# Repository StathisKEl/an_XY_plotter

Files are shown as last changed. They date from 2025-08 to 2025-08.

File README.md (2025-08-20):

An XY plotter that places an array of a Hall sensor and a strong magnet connected to two pieces of soft iron over specific points on a metal sheet and measures the changes in magnetic induction as the above array is moved from one point to another. From the measurements stored on an SD card, as well as the points of interest stored on the same SD card, useful conclusions can be drawn about the condition of the metal sheet.

The code inside the code_XY_plotter.ino file is under the GNU General Public v3.0 license and the hardware of the XY plotter such as the eagle pcb files and the eagle library files is under the CERN Open Hardware Version 2 - Strongly Reciprocal license. Also all the files of the 3D parts are under the Creative Commons Attribution Share Alike 4.0 International license. All the informations about the GNU General Public v3.0 license can be found in the GNU GPLv3 license.txt file, all the informations about the CERN Open Hardware Version 2 - Strongly Reciprocal license can be found in the CERN OHL S 2.0 license.txt file and all the informations about the Creative Commons Attribution Share Alike 4.0 International license can be found in the CC-BY-SA-4.0 license.txt file.

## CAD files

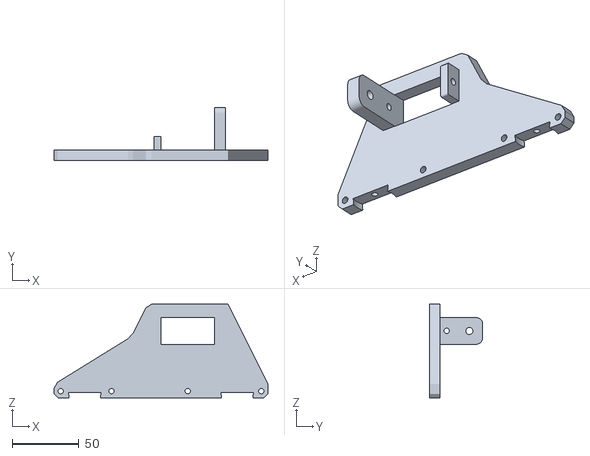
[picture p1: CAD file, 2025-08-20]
3D_printing_files/Base Plate Bottom.stl
160.0 x 40.0 x 70.0

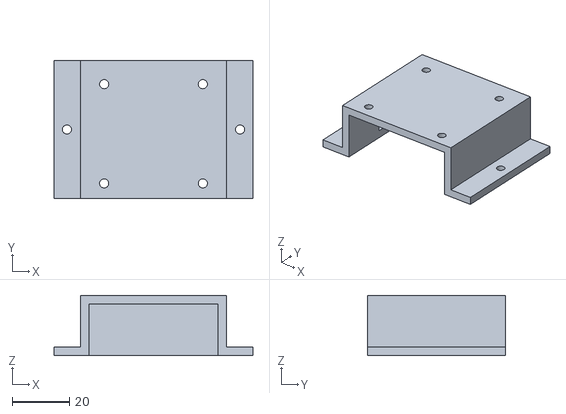
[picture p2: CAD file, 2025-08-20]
3D_printing_files/Sensor Holder Second Part v5.stl
69.4 x 48.0 x 21.0

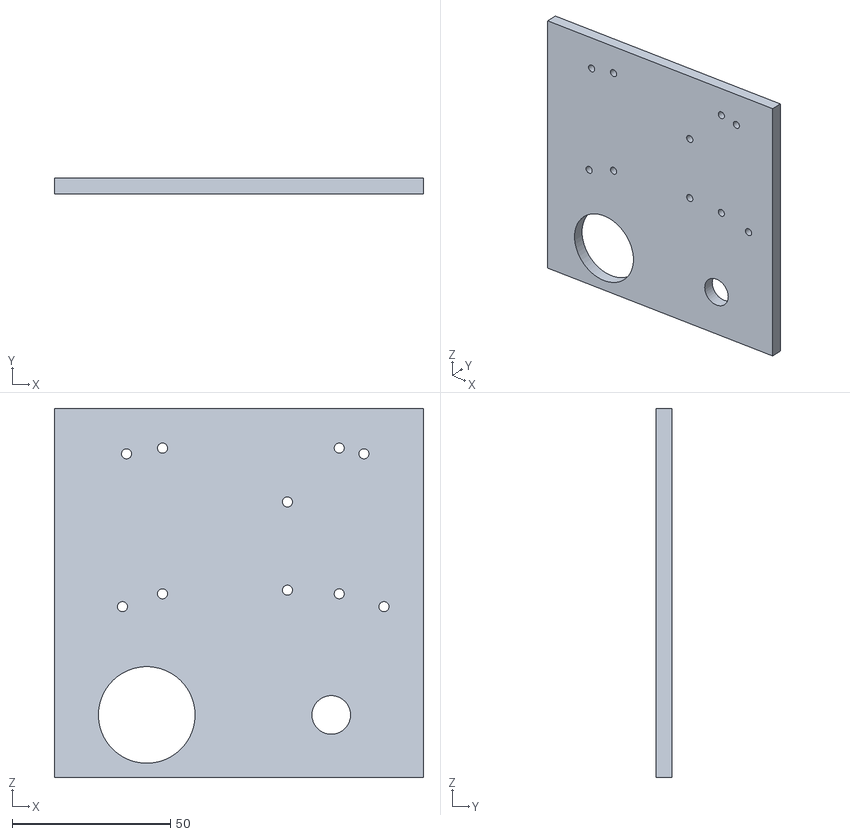
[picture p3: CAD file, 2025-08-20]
3D_printing_files/PCB Base v4.stl
116.5 x 5.00 x 116.5

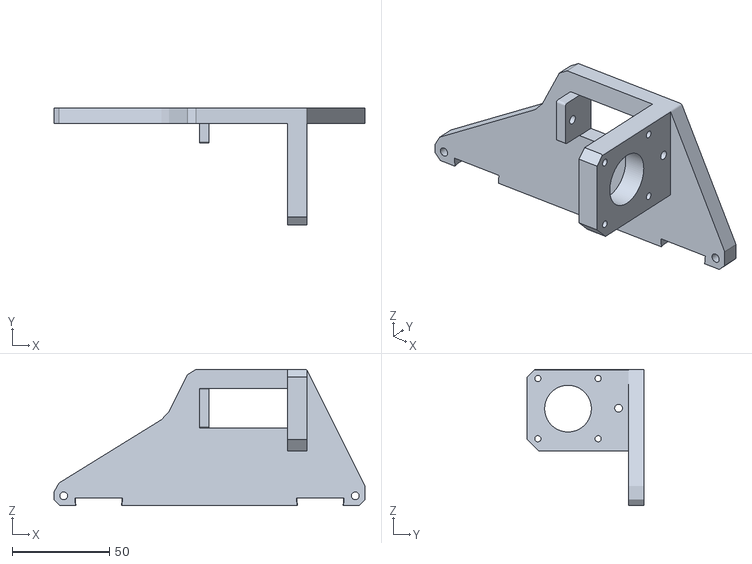
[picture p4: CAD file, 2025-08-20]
3D_printing_files/Base Plate Top.stl
160.0 x 60.0 x 70.0

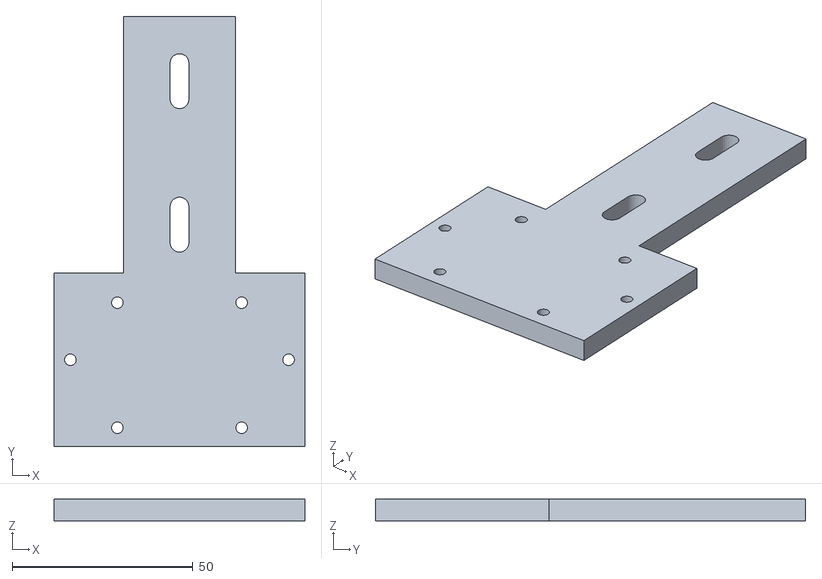
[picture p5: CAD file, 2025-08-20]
3D_printing_files/Sensor Holder First Part v3.stl
69.4 x 119.0 x 6.00

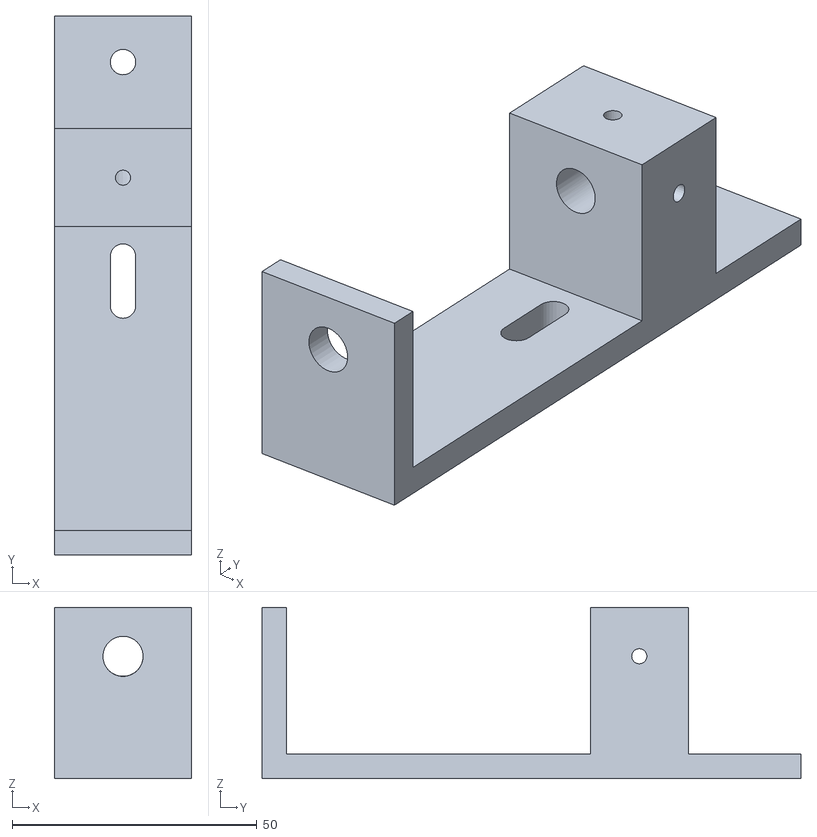
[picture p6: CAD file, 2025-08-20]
3D_printing_files/Holder v8.stl
28.0 x 110.0 x 35.0

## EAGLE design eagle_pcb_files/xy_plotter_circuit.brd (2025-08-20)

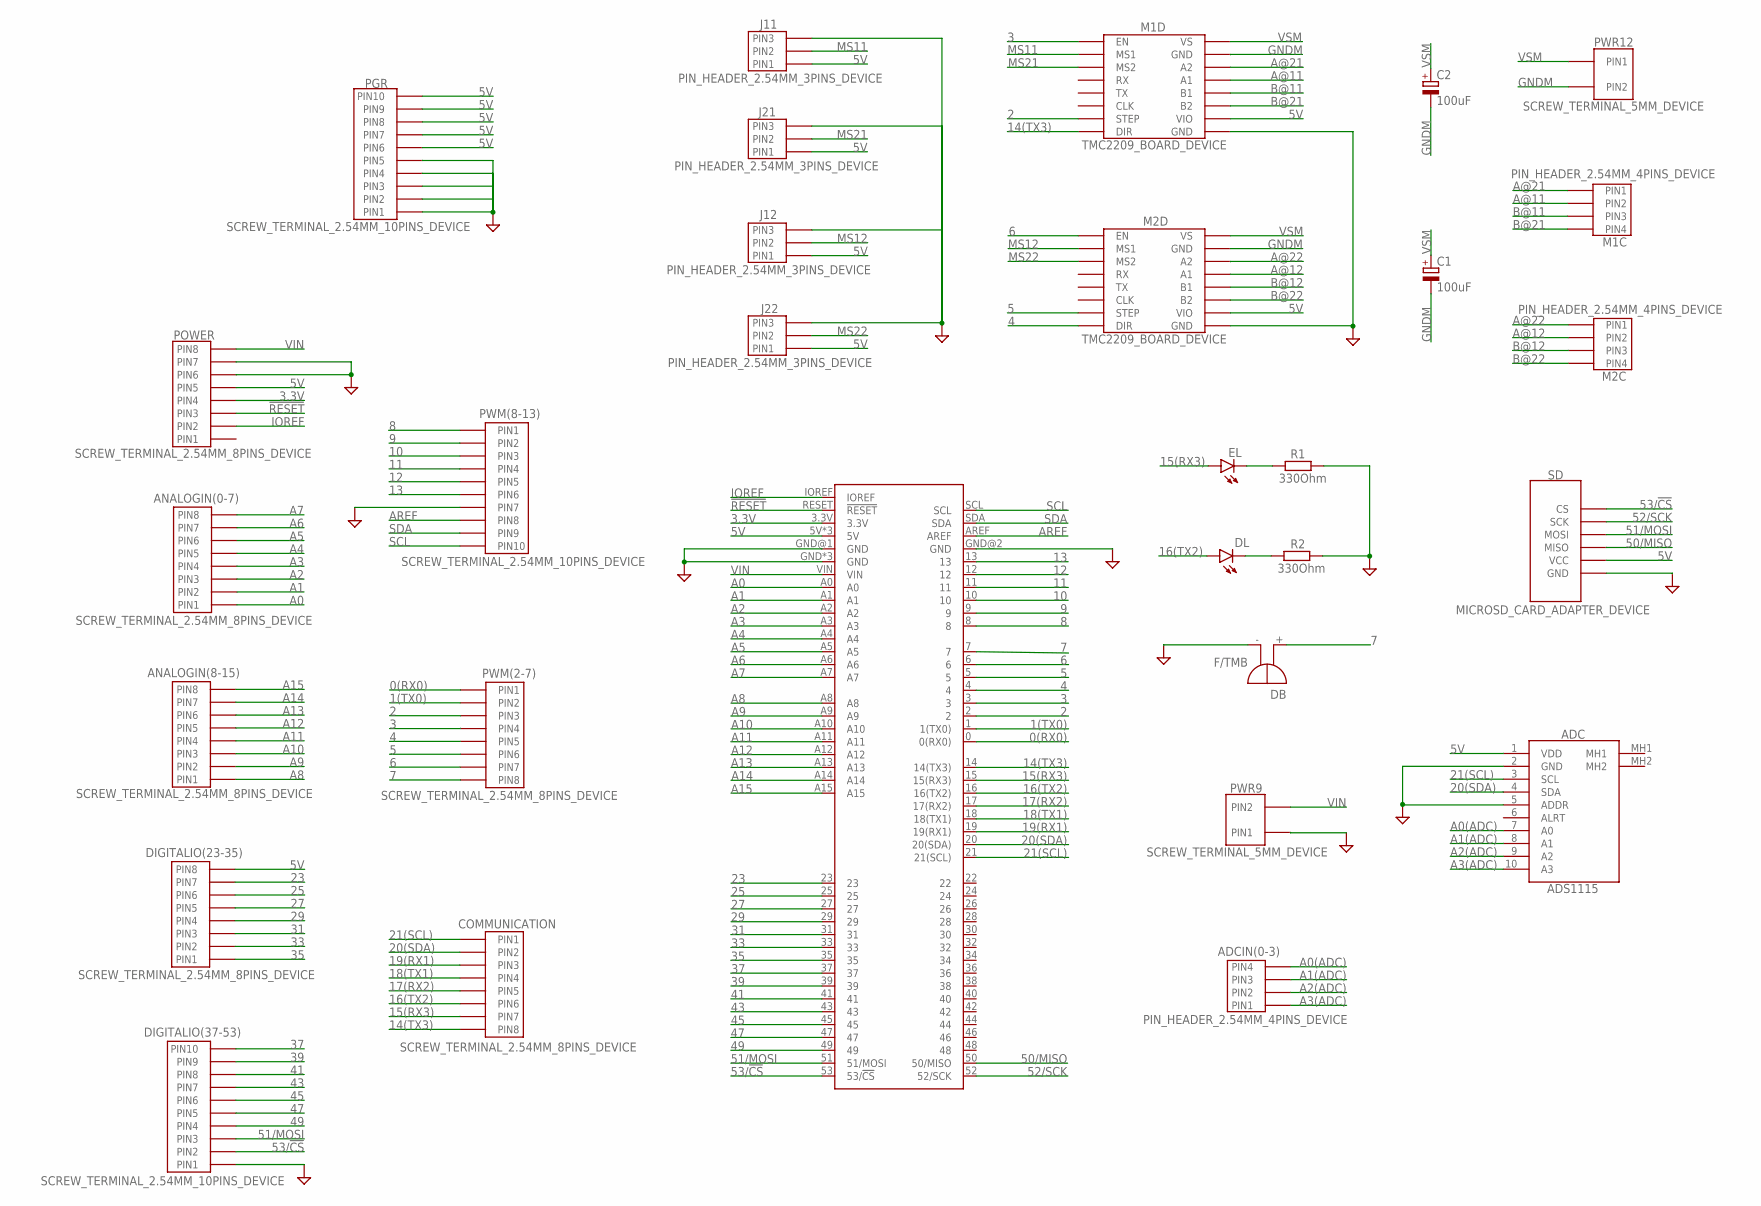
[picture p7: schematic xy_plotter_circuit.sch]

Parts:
ADC: ADS1115
ADCIN(0-3): PIN_HEADER_2.54MM_4PINS_DEVICE; PIN_HEADER_2.54MM_4PINS_FOOTPRINT
ANALOGIN(0-7), ANALOGIN(8-15): SCREW_TERMINAL_2.54MM_8PINS_DEVICE; SCREW_TERMINAL_2.54MM_8PINS_FOOTPRINT
ARDUINO: ARDUINO_MEGA_R3FULL; ARDUINO_MEGA_NO_SILK
C1, C2: 100uF; E2,5-7
COMMUNICATION: SCREW_TERMINAL_2.54MM_8PINS_DEVICE; SCREW_TERMINAL_2.54MM_8PINS_FOOTPRINT
DB: F/TMB
DIGITALIO(23-35): SCREW_TERMINAL_2.54MM_8PINS_DEVICE; SCREW_TERMINAL_2.54MM_8PINS_FOOTPRINT
DIGITALIO(37-53): SCREW_TERMINAL_2.54MM_10PINS_DEVICE; SCREW_TERMINAL_2.54MM_10PINS_FOOTPRINT
DL: LED3MM
EL: LED3MM
J11, J12, J21, J22: PIN_HEADER_2.54MM_3PINS_DEVICE; PIN_HEADER_2.54MM_3PINS_FOOTPRINT
M1C, M2C: PIN_HEADER_2.54MM_4PINS_DEVICE; PIN_HEADER_2.54MM_4PINS_FOOTPRINT
M1D, M2D: TMC2209_BOARD_DEVICE; TMC2209_BOARD_FOOTPRINT
PGR: SCREW_TERMINAL_2.54MM_10PINS_DEVICE; SCREW_TERMINAL_2.54MM_10PINS_FOOTPRINT
POWER: SCREW_TERMINAL_2.54MM_8PINS_DEVICE; SCREW_TERMINAL_2.54MM_8PINS_FOOTPRINT
PWM(2-7): SCREW_TERMINAL_2.54MM_8PINS_DEVICE; SCREW_TERMINAL_2.54MM_8PINS_FOOTPRINT
PWM(8-13): SCREW_TERMINAL_2.54MM_10PINS_DEVICE; SCREW_TERMINAL_2.54MM_10PINS_FOOTPRINT
PWR9, PWR12: SCREW_TERMINAL_5MM_DEVICE; SCREW_TERMINAL_5MM_FOOTPRINT
R1, R2: 330Ohm; 0207/7
SD: MICROSD_CARD_ADAPTER_DEVICE; MICROSD_CARD_ADAPTER_FOOTPRINT

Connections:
0(RX0): ARDUINO.0 (0(RX0)), PWM(2-7).PIN1
1(TX0): ARDUINO.1 (1(TX0)), PWM(2-7).PIN2
2: ARDUINO.2, M1D.STEP, PWM(2-7).PIN3
3: ARDUINO.3, M1D.EN, PWM(2-7).PIN4
3.3V: ARDUINO.3.3V, POWER.PIN4
4: ARDUINO.4, M2D.DIR, PWM(2-7).PIN5
5: ARDUINO.5, M2D.STEP, PWM(2-7).PIN6
5V: ADC.1 (VDD), ARDUINO.5V, ARDUINO.5V@1 (5V), ARDUINO.5V@2 (5V), DIGITALIO(23-35).PIN8, J11.PIN1, J12.PIN1, J21.PIN1, J22.PIN1, M1D.VIO, M2D.VIO, PGR.PIN6, PGR.PIN7, PGR.PIN8, PGR.PIN9, PGR.PIN10, POWER.PIN5, SD.VCC
6: ARDUINO.6, M2D.EN, PWM(2-7).PIN7
7: ARDUINO.7, DB.+, PWM(2-7).PIN8
8: ARDUINO.8, PWM(8-13).PIN1
9: ARDUINO.9, PWM(8-13).PIN2
10: ARDUINO.10, PWM(8-13).PIN3
11: ARDUINO.11, PWM(8-13).PIN4
12: ARDUINO.12, PWM(8-13).PIN5
13: ARDUINO.13, PWM(8-13).PIN6
14(TX3): ARDUINO.14 (14(TX3)), COMMUNICATION.PIN8, M1D.DIR
15(RX3): ARDUINO.15 (15(RX3)), COMMUNICATION.PIN7, EL.A
16(TX2): ARDUINO.16 (16(TX2)), COMMUNICATION.PIN6, DL.A
17(RX2): ARDUINO.17 (17(RX2)), COMMUNICATION.PIN5
18(TX1): ARDUINO.18 (18(TX1)), COMMUNICATION.PIN4
19(RX1): ARDUINO.19 (19(RX1)), COMMUNICATION.PIN3
20(SDA): ADC.4 (SDA), ARDUINO.20 (20(SDA)), COMMUNICATION.PIN2
21(SCL): ADC.3 (SCL), ARDUINO.21 (21(SCL)), COMMUNICATION.PIN1
23: ARDUINO.23, DIGITALIO(23-35).PIN7
25: ARDUINO.25, DIGITALIO(23-35).PIN6
27: ARDUINO.27, DIGITALIO(23-35).PIN5
29: ARDUINO.29, DIGITALIO(23-35).PIN4
31: ARDUINO.31, DIGITALIO(23-35).PIN3
33: ARDUINO.33, DIGITALIO(23-35).PIN2
35: ARDUINO.35, DIGITALIO(23-35).PIN1
37: ARDUINO.37, DIGITALIO(37-53).PIN10
39: ARDUINO.39, DIGITALIO(37-53).PIN9
41: ARDUINO.41, DIGITALIO(37-53).PIN8
43: ARDUINO.43, DIGITALIO(37-53).PIN7
45: ARDUINO.45, DIGITALIO(37-53).PIN6
47: ARDUINO.47, DIGITALIO(37-53).PIN5
49: ARDUINO.49, DIGITALIO(37-53).PIN4
50/MISO: ARDUINO.50 (50/MISO), SD.MISO
51/MOSI: ARDUINO.51 (51/MOSI), DIGITALIO(37-53).PIN3, SD.MOSI
52/SCK: ARDUINO.52 (52/SCK), SD.SCK
53/!CS: ARDUINO.53 (53/!CS), DIGITALIO(37-53).PIN2, SD.CS
!RESET: ARDUINO.RESET (!RESET), POWER.PIN3
A0: ANALOGIN(0-7).PIN1, ARDUINO.A0
A0(ADC): ADC.7 (A0), ADCIN(0-3).PIN4
A1: ANALOGIN(0-7).PIN2, ARDUINO.A1
A1(ADC): ADC.8 (A1), ADCIN(0-3).PIN3
A2: ANALOGIN(0-7).PIN3, ARDUINO.A2
A2(ADC): ADC.9 (A2), ADCIN(0-3).PIN2
A3: ANALOGIN(0-7).PIN4, ARDUINO.A3
A3(ADC): ADC.10 (A3), ADCIN(0-3).PIN1
A4: ANALOGIN(0-7).PIN5, ARDUINO.A4
A5: ANALOGIN(0-7).PIN6, ARDUINO.A5
A6: ANALOGIN(0-7).PIN7, ARDUINO.A6
A7: ANALOGIN(0-7).PIN8, ARDUINO.A7
A8: ANALOGIN(8-15).PIN1, ARDUINO.A8
A9: ANALOGIN(8-15).PIN2, ARDUINO.A9
A10: ANALOGIN(8-15).PIN3, ARDUINO.A10
A11: ANALOGIN(8-15).PIN4, ARDUINO.A11
A12: ANALOGIN(8-15).PIN5, ARDUINO.A12
A13: ANALOGIN(8-15).PIN6, ARDUINO.A13
A14: ANALOGIN(8-15).PIN7, ARDUINO.A14
A15: ANALOGIN(8-15).PIN8, ARDUINO.A15
A@11: M1C.PIN2, M1D.A1
A@12: M2C.PIN2, M2D.A1
A@21: M1C.PIN1, M1D.A2
A@22: M2C.PIN1, M2D.A2
AREF: ARDUINO.AREF, PWM(8-13).PIN8
B@11: M1C.PIN3, M1D.B1
B@12: M2C.PIN3, M2D.B1
B@21: M1C.PIN4, M1D.B2
B@22: M2C.PIN4, M2D.B2
GND: ADC.2 (GND), ADC.5 (ADDR), ARDUINO.GND, ARDUINO.GND@1 (GND), ARDUINO.GND@2 (GND), ARDUINO.GND@3 (GND), ARDUINO.GND@4 (GND), DB.-, DIGITALIO(37-53).PIN1, J11.PIN3, J12.PIN3, J21.PIN3, J22.PIN3, M1D.GND@2 (GND), M2D.GND@2 (GND), PGR.PIN1, PGR.PIN2, PGR.PIN3, PGR.PIN4, PGR.PIN5, POWER.PIN6, POWER.PIN7, PWM(8-13).PIN7, PWR9.PIN1, R1.2, R2.2, SD.GND
GNDM: C1.-, C2.-, M1D.GND@1 (GND), M2D.GND@1 (GND), PWR12.PIN2
IOREF: ARDUINO.IOREF, POWER.PIN2
MS11: J11.PIN2, M1D.MS1
MS12: J12.PIN2, M2D.MS1
MS21: J21.PIN2, M1D.MS2
MS22: J22.PIN2, M2D.MS2
unnamed: EL.K (C), R1.1
unnamed: DL.K (C), R2.1
SCL: ARDUINO.SCL, PWM(8-13).PIN10
SDA: ARDUINO.SDA, PWM(8-13).PIN9
VIN: ARDUINO.VIN, POWER.PIN8, PWR9.PIN2
VSM: C1.+, C2.+, M1D.VS, M2D.VS, PWR12.PIN1

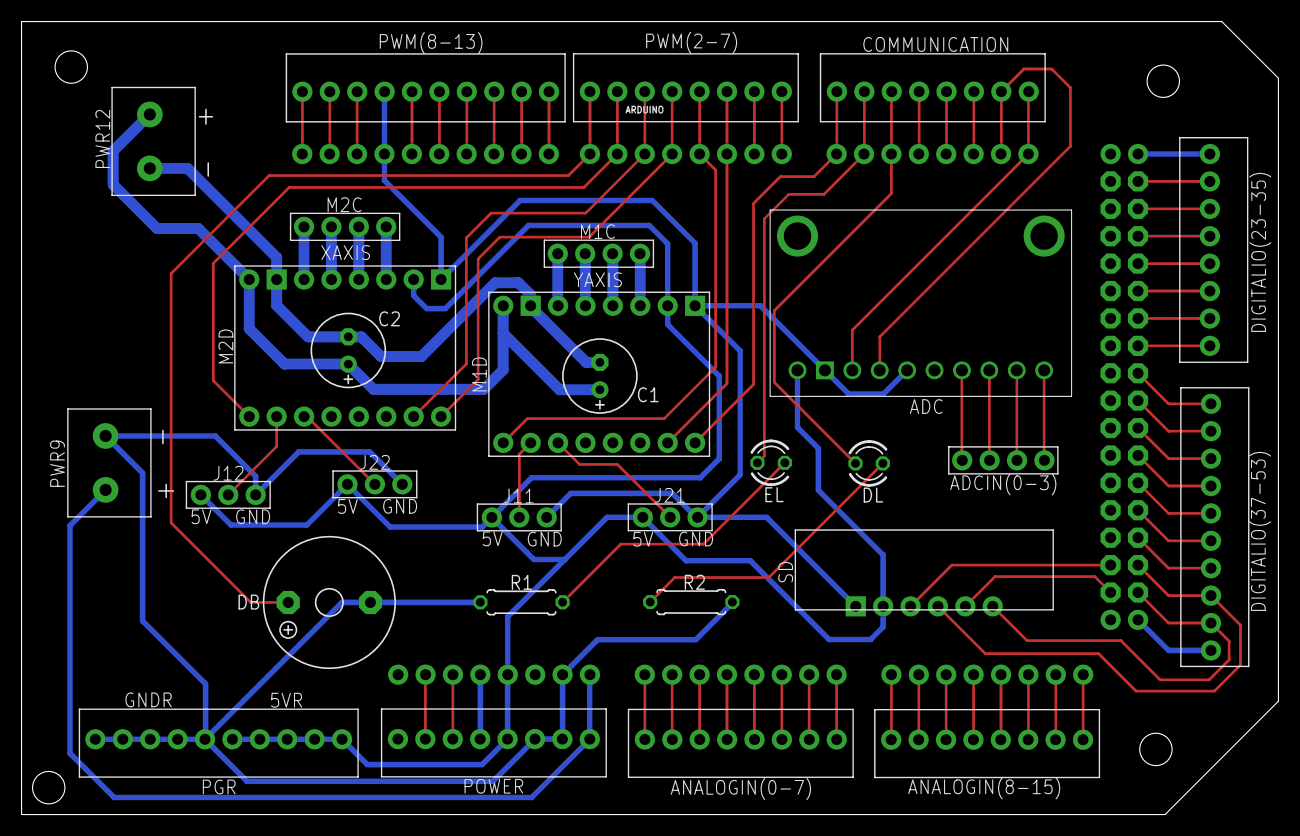
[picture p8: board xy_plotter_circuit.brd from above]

Board: 2 copper layers, 116.5 x 73.5 mm, 30 parts (0 on the bottom side), 85 nets.

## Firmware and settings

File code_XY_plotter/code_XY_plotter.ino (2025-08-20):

#include <SpeedyStepper.h>

#include <SPI.h>
#include <SD.h>

#include<Wire.h>
#include<ADS1115_WE.h> 


#define I2C_ADDRESS 0x48

#define warning_led 15
#define success_led 16
#define success_buzzer 7

#define EN_PIN_X 6
#define DIR_PIN_X 4
#define STEP_PIN_X 5
#define limit_switch_x 17

#define EN_PIN_Y 3
#define DIR_PIN_Y 14
#define STEP_PIN_Y 2
#define limit_switch_y 18

#define stop_button 19

ADS1115_WE adc = ADS1115_WE(I2C_ADDRESS);

const int width_metal = 230;
const int length_metal = 350;

const int microstep_setting_x = 8;
const int microstep_setting_y = 8;

volatile bool serious_error = false;

void homing_xy();
void get_content_line(unsigned long index_line, unsigned long num_char_line, int* information_line);
void go_point(int coordinate_x, int coordinate_y, float degrees_one_step_x, float degrees_one_step_y, float div_max_values_x, float div_max_values_y);
int write_measurement_coordinates(int coordinates_error);
//Uncomment this for plotting the magnetic flux density in real time.
//Caution: you can not use the SD card write functionality and the Serial Print functionality at the same time.
//void plot_measurement_coordinates();
//Uncomment this for finding the X and Y axis in the physical workspace.
//void config(int coordinate_x, int coordinate_y, float degrees_one_step_x, float degrees_one_step_y);


File myFile;

SpeedyStepper stepper_x;
SpeedyStepper stepper_y;

void setup()
{
  int num_lines_file = 0, general_error = 0, i = 1, k, information_line[3] = {0}, writing_error;
  unsigned long size_file, pos_last_char_line[100], index_line, num_char_line;
  float degrees_one_step_x, degrees_one_step_y, width_metal_steps, length_metal_steps, div_max_values_x, div_max_values_y;
  char char_file;

  //Uncomment this for plotting the magnetic flux density in real time.
  //Caution: you can not use the SD card write functionality and the Serial Print functionality at the same time.
  //Serial.begin(9600);

  Wire.begin();

  attachInterrupt(digitalPinToInterrupt(stop_button), turn_off_motors, FALLING);

  pinMode(success_buzzer, OUTPUT);
  pinMode(warning_led, OUTPUT);
  pinMode(success_led, OUTPUT);

  stepper_x.connectToPins(STEP_PIN_X, DIR_PIN_X);
  stepper_y.connectToPins(STEP_PIN_Y, DIR_PIN_Y);

  pinMode(EN_PIN_X, OUTPUT);
  pinMode(EN_PIN_Y, OUTPUT);
  pinMode(limit_switch_x, INPUT_PULLUP);
  pinMode(limit_switch_y, INPUT_PULLUP);
  pinMode(stop_button, INPUT_PULLUP);

  digitalWrite(EN_PIN_X, LOW);
  digitalWrite(EN_PIN_Y, LOW);

  pos_last_char_line[0] = 0;

  if(!adc.init())
  {
    // Ο ADC δεν συνδέθηκε.
    general_error = 1;
  }

  adc.setVoltageRange_mV(ADS1115_RANGE_6144);
  
  adc.setConvRate(ADS1115_860_SPS);

  
  if (!SD.begin()) 
  {
    // Η κάρτα microSD δεν αρχικοποιήθηκε.
    general_error = 1;
  }
  else
  {
    if (SD.exists("CRD.csv"))
    {
      myFile = SD.open("CRD.csv");
      if (!myFile)
      {
        // Το αρχείο CRD δεν άνοιξε.
        general_error = 1;
      }
      else
      {
        size_file = myFile.size();
        while (myFile.available()>0) 
        {
          char_file = myFile.read();
          if (char_file=='\n')
          {
            num_lines_file += 1;
            pos_last_char_line[i] = myFile.position();
            i += 1;
          }
        }
        myFile.close();
      }
    }
    else
    {
      // Το αρχείο CRD δεν υπάρχει στην κάρτα microSD.
      general_error = 1;
    }
  }
  
  degrees_one_step_x = 1.8/microstep_setting_x;
  degrees_one_step_y = 1.8/microstep_setting_y;
  
  width_metal_steps = (width_metal*0.028125)/(degrees_one_step_x*0.003134667506);
  length_metal_steps = (length_metal*0.028125)/(degrees_one_step_y*0.003134025412);
  div_max_values_x = 12500/width_metal_steps;
  div_max_values_y = 12500/length_metal_steps;

  homing_xy();

  //Uncomment this for finding the X and Y axis in the physical workspace.
  /*delay(1000);

  config(230 ,0, degrees_one_step_x, degrees_one_step_y);
  config(0, 0, degrees_one_step_x, degrees_one_step_y);
  config(0, 350, degrees_one_step_x, degrees_one_step_y);
  config(0, 0, degrees_one_step_x, degrees_one_step_y);*/

  delay(3000);

  if (SD.exists("MSR.txt"))
  {
    SD.remove("MSR.txt");
  }
  if (general_error==0)
  {
    for (k=0;k<num_lines_file+1;k++)
    {
      if (serious_error==true)
      {
        break;
      }
      index_line = pos_last_char_line[k];
      if (k==num_lines_file)
      {
        num_char_line = size_file - pos_last_char_line[k];
      }
      else
      {
        num_char_line = pos_last_char_line[k+1] - pos_last_char_line[k] - 2;
      }
      get_content_line(index_line, num_char_line, information_line);
      if (information_line[2]!=1)
      {
        go_point(information_line[0], information_line[1], degrees_one_step_x, degrees_one_step_y, div_max_values_x, div_max_values_y);
      }
      writing_error = write_measurement_coordinates(information_line[2]);
      //Uncomment this for plotting the magnetic flux density in real time.
      //Caution: you can not use the SD card write functionality and the Serial Print functionality at the same time.
      //plot_measurement_coordinates();
      if (writing_error==1)
      {
        digitalWrite(warning_led, HIGH);
        break;
      }
      delay(3000);
    }
  }
  else
  {
    digitalWrite(warning_led, HIGH);
  }
  
  if (general_error!=1 && writing_error!=1 && serious_error!=true)
  {
    stepper_x.setSpeedInStepsPerSecond(200);
    stepper_x.setAccelerationInStepsPerSecondPerSecond(100);
    stepper_y.setSpeedInStepsPerSecond(200);
    stepper_y.setAccelerationInStepsPerSecondPerSecond(100);

    stepper_x.moveToPositionInSteps(0);
    delay(100);
    stepper_y.moveToPositionInSteps(0);

    delay(1000);

    digitalWrite(EN_PIN_X, HIGH);
    digitalWrite(EN_PIN_Y, HIGH);
    
    delay(1000);

    digitalWrite(success_led, HIGH);
    digitalWrite(success_buzzer, HIGH);
    delay(5000);
    digitalWrite(success_buzzer, LOW);
  }
}

void loop()
{
}

void homing_xy()
{
  bool good_home_x, good_home_y;

  do {
  good_home_x = stepper_x.moveToHomeInSteps(1, 200.0, 76085, limit_switch_x);
  delay(100);
  good_home_y = stepper_y.moveToHomeInSteps(1, 200.0, 113751, limit_switch_y);
  } while (good_home_x==false || good_home_y==false);
}

void get_content_line(unsigned long index_line, unsigned long num_char_line, int* information_line)
{
  String coordinates_string = "", x_coordinate_string = "", y_coordinate_string = "";
  int pos_question_mark, coordinates_error = 0;
  char tpr_char;
  unsigned long j;
  
  myFile = SD.open("CRD.csv");
  if (myFile)
  {
    myFile.seek(index_line);
    for (j=0;j<num_char_line;j++)
    {
      coordinates_string += (char)myFile.read();
    }
    myFile.close();
  }
  pos_question_mark = coordinates_string.indexOf(';');
  if (pos_question_mark!=-1)
  {
    if (pos_question_mark>0 && pos_question_mark<coordinates_string.length()-1)
    {
      for (j=0;j<coordinates_string.length();j++)
      {
        tpr_char = coordinates_string.charAt(j);
        if (tpr_char==';')
        {
          continue;
        }
        if (isDigit(tpr_char))
        {
          if (j<pos_question_mark)
          {
            x_coordinate_string += tpr_char;
          }
          if (j>pos_question_mark)
          {
            y_coordinate_string += tpr_char;
          }
        } 
        else
        {
          // Συντεταγμένες με έναν ή περισσότερους μη αριθμητικούς χαρακτήρες.
          coordinates_error = 1;
          break;
        }
      }
    }
    else
    {
      // Απουσία μιας εκ των δυο συντεταγμένων.
      coordinates_error = 1;
    }
  }
  else
  {
    // Απουσία του χαρακτήρα ;.
    coordinates_error = 1;
  }

  if (coordinates_error!=1 && (x_coordinate_string.toInt()>230 || y_coordinate_string.toInt()>350))
  {
    // Μια εκ των δυο συντεταγμένων ή και οι δυο συντεταγμένες είναι out of range.
    coordinates_error = 1;
  }

  if(coordinates_error!=1)
  {
    *information_line = x_coordinate_string.toInt();
    *(information_line+1) = y_coordinate_string.toInt();
  }

  *(information_line+2) = coordinates_error;
}

void go_point(int coordinate_x, int coordinate_y, float degrees_one_step_x, float degrees_one_step_y, float div_max_values_x, float div_max_values_y)
{
  float x_coordinate_steps, y_coordinate_steps, difference_x, difference_y;
  double speed_per_sec_x, speed_per_sec_y;

  x_coordinate_steps = (-coordinate_x*0.028125)/(degrees_one_step_x*0.003134667506);
  y_coordinate_steps = (-coordinate_y*0.028125)/(degrees_one_step_y*0.003134025412);

  difference_x = x_coordinate_steps - (float)stepper_x.getCurrentPositionInSteps();
  difference_y = y_coordinate_steps - (float)stepper_y.getCurrentPositionInSteps();
  difference_x = abs(difference_x);
  difference_y = abs(difference_y);

  if (difference_x>difference_y)
  {
    speed_per_sec_x = (div_max_values_x*pow(difference_x,2)+div_max_values_y*difference_y*difference_x)/(difference_x+difference_y);
    speed_per_sec_y = (div_max_values_x*pow(difference_x,2)*difference_y+div_max_values_y*pow(difference_y,2)*difference_x)/(difference_x*(difference_x+difference_y));
  }
  else if (difference_x<difference_y)
  {
    speed_per_sec_y = (div_max_values_y*pow(difference_y,2)+div_max_values_x*difference_y*difference_x)/(difference_x+difference_y);
    speed_per_sec_x = (div_max_values_x*pow(difference_x,2)*difference_y+div_max_values_y*pow(difference_y,2)*difference_x)/(difference_y*(difference_x+difference_y));
  }
  else
  {
    speed_per_sec_x = (div_max_values_x*difference_x)/2+(div_max_values_y*difference_y)/2;
    speed_per_sec_y = (div_max_values_x*difference_x)/2+(div_max_values_y*difference_y)/2;
  }

  stepper_x.setSpeedInStepsPerSecond((float)speed_per_sec_x);
  stepper_x.setAccelerationInStepsPerSecondPerSecond((float)speed_per_sec_x/2);
  stepper_y.setSpeedInStepsPerSecond((float)speed_per_sec_y);
  stepper_y.setAccelerationInStepsPerSecondPerSecond((float)speed_per_sec_y/2);

  stepper_x.setupMoveInSteps((long)x_coordinate_steps);
  stepper_y.setupMoveInSteps((long)y_coordinate_steps);

  while((stepper_x.motionComplete()==false) || (stepper_y.motionComplete()==false))
  {
    stepper_x.processMovement();
    stepper_y.processMovement();
  }
}

int write_measurement_coordinates(int coordinates_error)
{
  int writing_error = 0;
  float msr_value;
  char buff[7];
  myFile = SD.open("MSR.txt", FILE_WRITE);
  if (myFile)
  {
    if (coordinates_error!=1)
    {
      adc.setCompareChannels(ADS1115_COMP_0_GND);
      adc.startSingleMeasurement();
      while(adc.isBusy()){}
      msr_value = adc.getResult_mV();
      msr_value = map(msr_value, 500, 4500, -64, 64);
      dtostrf(msr_value, 6, 3, buff);
      buff[6]='\n';
      myFile.write(buff, 7);
    }
    else
    {
      myFile.println('!');
    }
    myFile.close();
  }
  else
  {
    // Αδυναμία πρόσβασης της πλακέτας Arduino στα δεδομένα του αρχείου MSR.
    writing_error = 1;
  }
  return writing_error;
}

//Uncomment this for plotting the magnetic flux density in real time.
//Caution: you can not use the SD card write functionality and the Serial Print functionality at the same time.
/*void plot_measurement_coordinates()
{
  float msr_value;

  adc.setCompareChannels(ADS1115_COMP_0_GND);
  adc.startSingleMeasurement();
  while(adc.isBusy()){}
  msr_value = adc.getResult_mV();
  msr_value = map(msr_value, 500, 4500, -64, 64);
  Serial.println(msr_value);
}*/

void turn_off_motors()
{
  digitalWrite(EN_PIN_X, HIGH);
  digitalWrite(EN_PIN_Y, HIGH);

  serious_error = true;
}

//Uncomment this for finding the X and Y axis in the physical workspace.
/*void config(int coordinate_x, int coordinate_y, float degrees_one_step_x, float degrees_one_step_y)
{
  float x_coordinate_steps, y_coordinate_steps;
  
  x_coordinate_steps = (-coordinate_x*0.028125)/(degrees_one_step_x*0.003134667506);
  y_coordinate_steps = (-coordinate_y*0.028125)/(degrees_one_step_y*0.003134025412);

  stepper_x.setSpeedInStepsPerSecond(200);
  stepper_x.setAccelerationInStepsPerSecondPerSecond(100);
  stepper_y.setSpeedInStepsPerSecond(200);
  stepper_y.setAccelerationInStepsPerSecondPerSecond(100);

  stepper_x.setupMoveInSteps((long)x_coordinate_steps);
  stepper_y.setupMoveInSteps((long)y_coordinate_steps);

  while((stepper_x.motionComplete()==false) || (stepper_y.motionComplete()==false))
  {
    stepper_x.processMovement();
    stepper_y.processMovement();
  }
}*/

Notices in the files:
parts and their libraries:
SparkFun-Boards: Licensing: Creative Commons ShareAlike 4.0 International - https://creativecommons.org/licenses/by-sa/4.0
